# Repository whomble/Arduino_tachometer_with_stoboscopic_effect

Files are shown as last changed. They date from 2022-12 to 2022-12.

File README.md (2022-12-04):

# Arduino_tachometer_with_stoboscopic_effect



The purpose of this tool is to measure any rotation speed with the same accuracy as a commercial product,
it can also blink at afrequency defined by the user to match the roatation of anything up to 1Khz.

It can be powered with usb (5V) or with a 12V power supply, when it's connected to 12V the tachometer can output 12V (20A max) at the blinking frequency. 
Since my workshop has a 12V power line to feed my LED lights and tools this allow me to blink all my lights simultaneously to analyze the rotation of any tool.

The left gift show my spindle's CNC at 12 000rpm with the matching frequency. The other gift show the same setup with a slightly different blinking frequency.

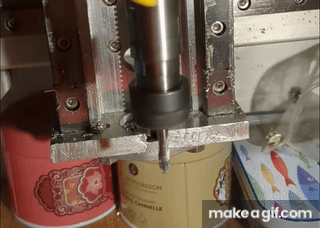
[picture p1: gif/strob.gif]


# Part list
| Part | Quantity | Cost |
|- | - | - |
| Arduino Nano | 1 | 5€ |
| IR barrirer sensor | 1 | 2€ |
| White LED | 1 | 0€ |
| Male + female jack connector| 1 | 3€ |
| 0.96" OLED display | 1 | 3€ |
| IRFZ44N Mosfet | 1 | 3€ |
| 3 pos sliding switch | 1 | 2€ |
| Rotary encoder | 1 | 2€ |
| TC4428 Mosfet driver | 1 | 5€ |

# 3D Printing

In most of my design I normally use screws for assembly but this time I wanted the most compact tool as possible so there is just 2 shells which can be hot glue together the everithing is wired correctly and tested. 
You can draw a bigger shell if you are more confortable with screws or if you aren't sure of the wirring

The two shells are printed with standard PLA 20% infil 3 wals and 3/4 top/bottom layers.

All components should properly fit in the case as shown bellow. I couldn't found the proper OLED display on GrabCad but the real one fit perfectly.

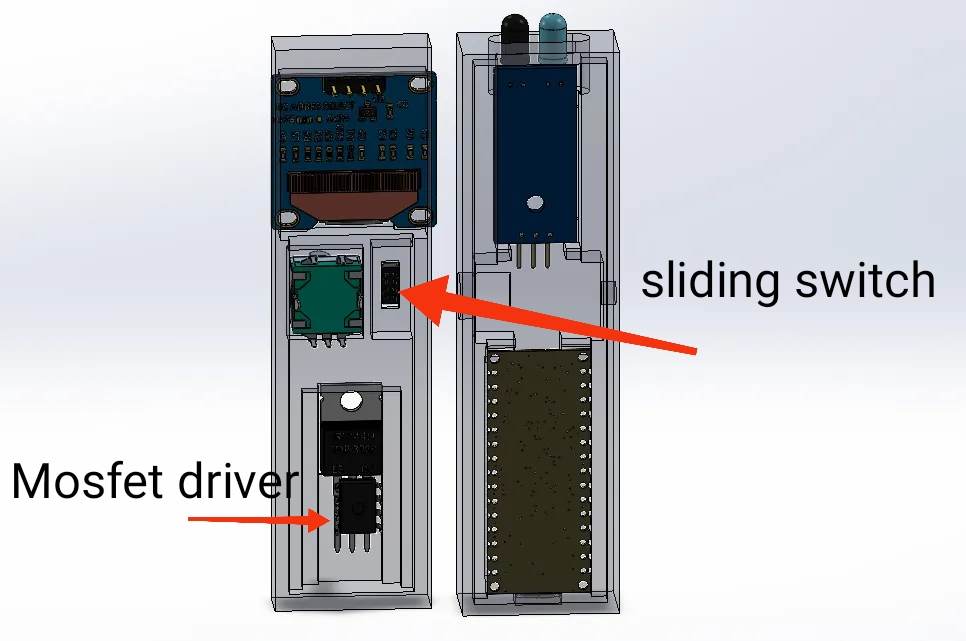
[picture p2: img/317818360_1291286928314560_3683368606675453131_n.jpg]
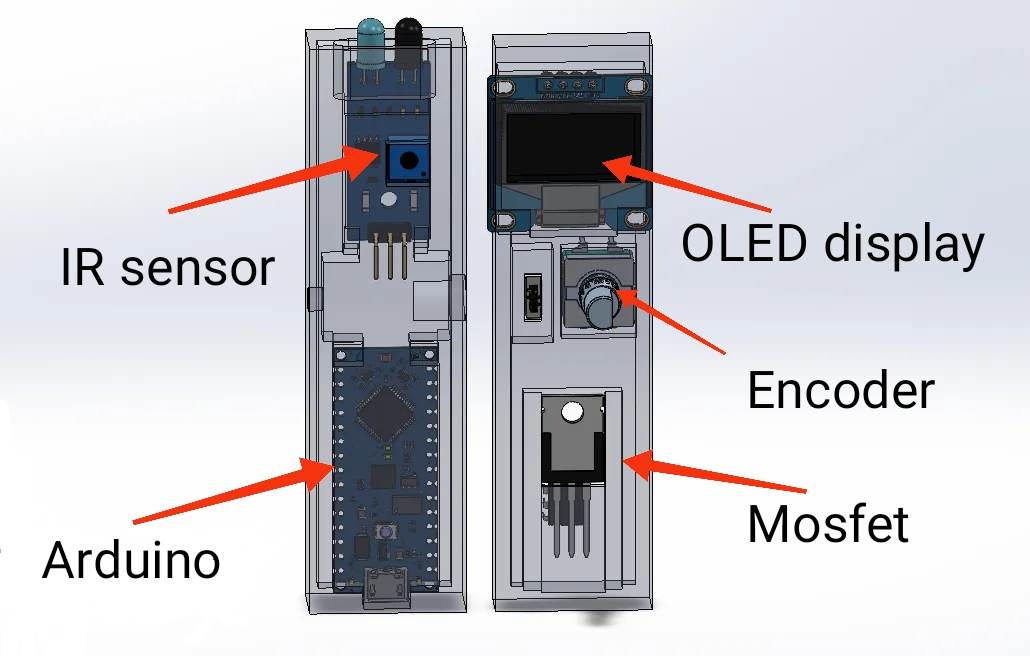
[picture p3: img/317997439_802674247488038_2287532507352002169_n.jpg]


# Wirring

The wirring isn't verry complicated, the only tricky part is the mosfet wirring.
Since its a N-Channel Mosfet the drain (middle part) is connected to the output and the source to the power suply's ground.

The gate is connected to a non inverting output from the Mosfet driver, and the driver itself is powered by the 12V and the signal is send by a PWM pin from the arduino.

I'll recommand you to use a small piece of perfboard to wire the mosfet and the driver properly! And please make sure tu use the appropriate wire thickness according to the current value.

All the others connextion can be found on the schematic below and in the code!

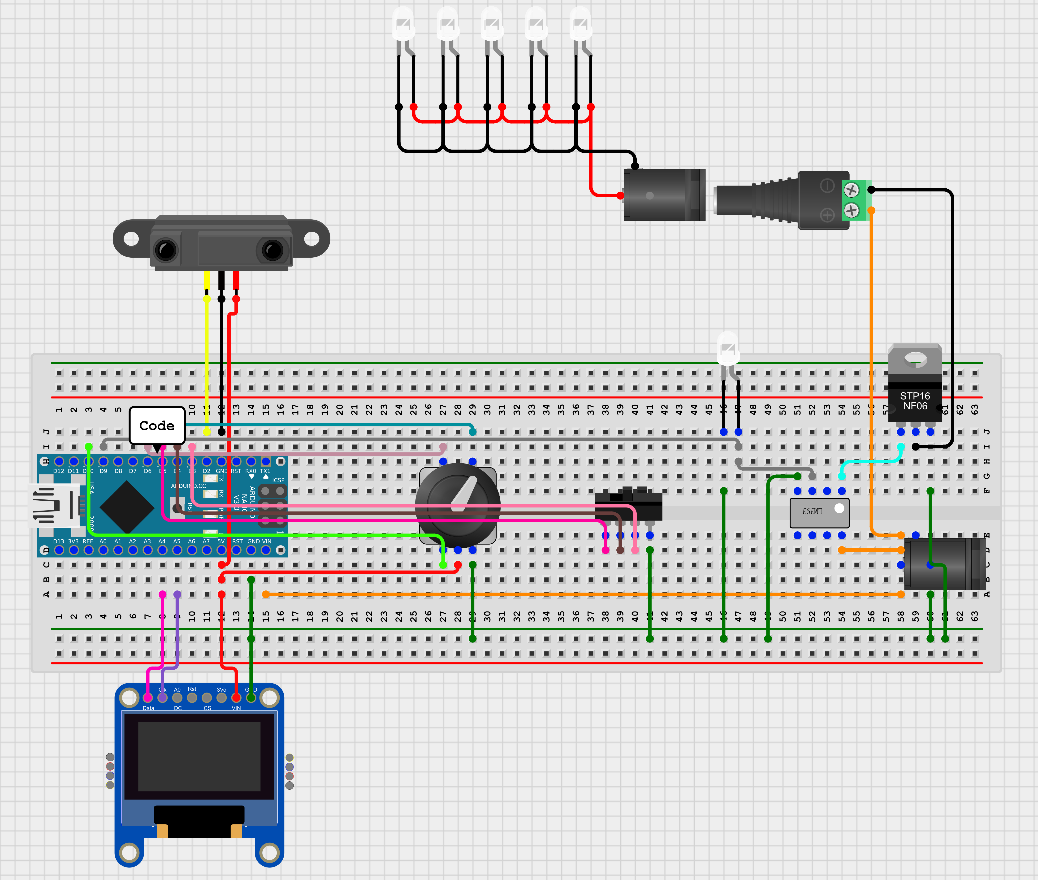
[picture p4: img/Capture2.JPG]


# Code

The code is availlable [here](code/tachostrob.ino) nothing specific in this one except interuption but you can find a lots tutorial about that 

# Tests and assembly

Please don't made the same error as me and test every functionnality before glueing the two parts

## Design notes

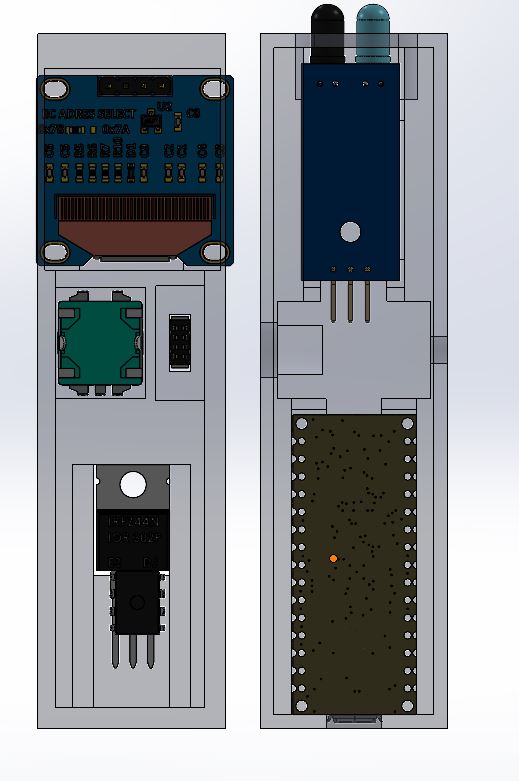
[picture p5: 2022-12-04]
img/face arriere.JPG

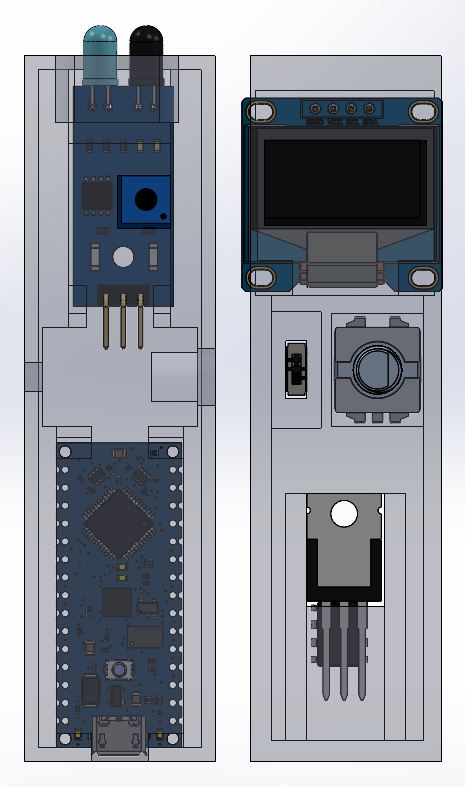
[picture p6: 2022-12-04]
img/face avant.JPG

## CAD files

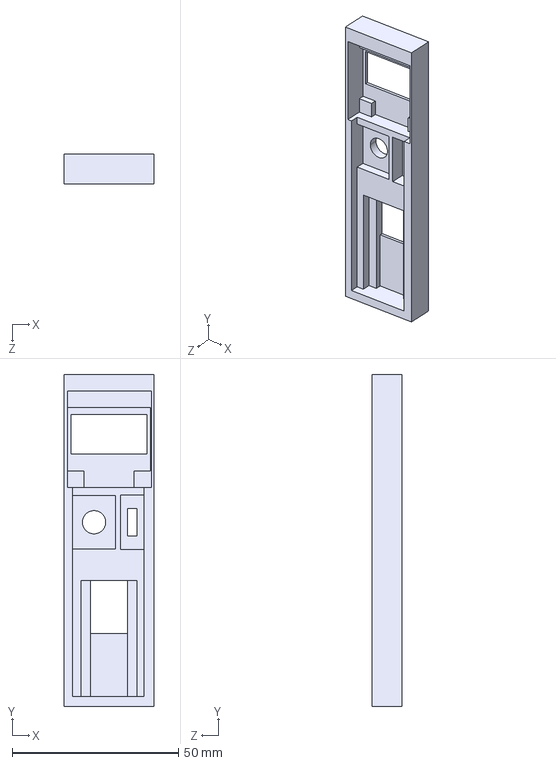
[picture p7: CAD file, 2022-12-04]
3D/step/dessus.STEP
27.0 x 100.0 x 9.00 mm

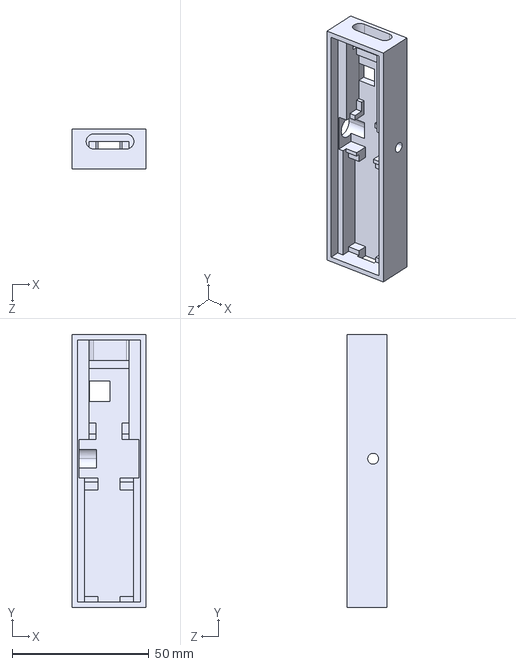
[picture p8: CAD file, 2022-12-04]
3D/step/dessous.STEP
27.0 x 100.0 x 14.5 mm

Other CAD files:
3D/stl/dessous.STL
3D/stl/dessus.STL

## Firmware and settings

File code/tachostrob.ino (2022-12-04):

#include <Arduino.h>

#include <SPI.h>
#include <Wire.h>
#include <Adafruit_GFX.h>
#include <Adafruit_SSD1306.h>
#define SCREEN_WIDTH 128 // OLED display width, in pixels
#define SCREEN_HEIGHT 64 // OLED display height, in pixels
#define OLED_RESET     -1 // Reset pin # (or -1 if sharing Arduino reset pin)
#define SCREEN_ADDRESS 0x3c ///< See datasheet for Address; 0x3D for 128x64, 0x3C for 2from aliexpress
Adafruit_SSD1306 display(SCREEN_WIDTH, SCREEN_HEIGHT, &Wire, OLED_RESET);
unsigned long rpmtime;
float rpmfloat = 10000;
unsigned int rpm;
bool tooslow = 1;
long delai1;
long delai2;
bool on = 0;
bool strobe = 0;
int counter = 0;
int aState;
int aLastState;
int Mode = 1;
int clic = 1;
int strob_step = 30;
#define clk 7
#define dt 6
#define rotsw 10
#define led 9

void setup() {
  
  display.begin(SSD1306_SWITCHCAPVCC, 0x3c);
  display.setTextSize(2);
  display.setTextColor(WHITE);
  display.clearDisplay();
  display.display();
  TCCR1A = 0;
  TCCR1B = 0;
  TCCR2B = 0;
  TCCR1B |= (1 << CS12); //Prescaler 256
  TCCR2B |= (1 << CS12); //Prescaler 256
  TIMSK1 |= (1 << TOIE1); //enable timer overflow
  pinMode(2, INPUT);
  pinMode(3, INPUT_PULLUP);//Sliding switch
  pinMode(4, INPUT_PULLUP);//Sliding switch
  pinMode(5, INPUT_PULLUP); //Sliding switch
  pinMode(6, INPUT_PULLUP);//Rotary 
  pinMode(7, INPUT_PULLUP);//Rotary 
  pinMode(10, INPUT_PULLUP); //Rotary switch
  pinMode(9, OUTPUT);//led strobe
  attachInterrupt(0, RPM, FALLING);
  aLastState = digitalRead(clk);
}

ISR(TIMER1_OVF_vect) {
  tooslow = 1;
}

void loop() {


  if (digitalRead(3) == 0) {
    Mode = 1; //Measure speed
  }
  else if (digitalRead(4) == 0) {
    Mode = 2; //Blink at the same rate as the roation
  }
  else if (digitalRead(5) == 0) {
    Mode = 3; // Select a specific speed with the rotary encoder
  }
  switch (Mode) {
    case 1: // Just printing the value from the void RPM (line 180) on the screen 
      delay(1000);
      display.clearDisplay();
      display.setCursor(30, 5);
      display.println("Mode 1");
      if (tooslow == 1) {
        display.setCursor(30, 25);
        display.println("Slow!!");
        display.display();
        strobe = 1;
      }
      else {
        strobe = 0;
        rpmfloat = 120 / (rpmtime / 31250.00);
        rpm = round(rpmfloat);
        display.setCursor(16, 25);
        display.print(rpm);
        display.print(" rpm");
        display.setCursor(30, 45);
        display.print(rpm / 60);
        display.print(" Hz");
        display.display();

      }
      break;
    case 2:
      digitalWrite(led, (1 - digitalRead(2))); // if the IR reciever emit a signal the LED is off and vice versa
      if (TCNT1 > 65000) {
        display.clearDisplay();
        display.setCursor(30, 5);
        display.println("Mode 2");
        display.setCursor(20, 25);
        display.println("Blynk"); 
        display.display();
        TCNT1 = 0;
      }
      break;
    case 3:
      if (rpmfloat <= 60) { // limit the measurement from 1hz to 1Khz it can work below but the code can enter an infinite loop
        rpmfloat = 60;
      }
      if (rpmfloat > 60000) {
        rpmfloat = 60000;
      }
      if (digitalRead(10) == 0) { // change the mode of the rotary encoder
        clic ++;
        if (clic >= 5) {
          clic = 0;
        }
        delay(200);
      }
      switch (clic) { // each push on the rotary switch will increase the steps to choose the right frequency. The last case switch on the light at the choosen frequency
        case 0:
          strob_step = 3;
          readRotary();
          break;
        case 1:
          strob_step = 30;
          readRotary();
          break;
        case 2:
          strob_step = 60;
          readRotary();
          break;
        case 3:
          strob_step = 150;
          readRotary();
          break;
        case 4:
          digitalWrite(led, 1);
          delay(delai2);
          digitalWrite(led, 0);
          delay(delai1);
          break;
      }
      if (TCNT1 > 6500 && clic != 4) {
        rpm = round(rpmfloat);
        delai1 = round(54000 / rpmfloat); // the duty cicle is 10% it can be increase here if you want
        delai2 = round(6000 / rpmfloat);
        display.clearDisplay();
        display.setCursor(30, 5);
        display.println("Mode 3");
        display.setCursor(16, 25);
        display.print(rpm);
        display.print(" rpm");
        display.setCursor(30, 45);
        display.print(rpm / 60);
        display.print(" Hz");
        display.display();
        TCNT1 = 0;
      }
      break;
  }
}

void readRotary( ) {
  aState = digitalRead(clk); // Reads the "current" state of the outputA
  if (aState != aLastState) {
    if (digitalRead(dt) != aState) {
      rpmfloat = rpmfloat + strob_step;
    }
    else {
      rpmfloat = rpmfloat - strob_step;
    }
  }
  aLastState = aState;
}
void RPM () { // counter using interuption
  rpmtime = TCNT1;
  TCNT1 = 0;
  tooslow = 0;
}
